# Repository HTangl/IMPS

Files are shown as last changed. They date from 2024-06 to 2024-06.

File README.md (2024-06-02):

# IMPS
Variable Impedance Selector  

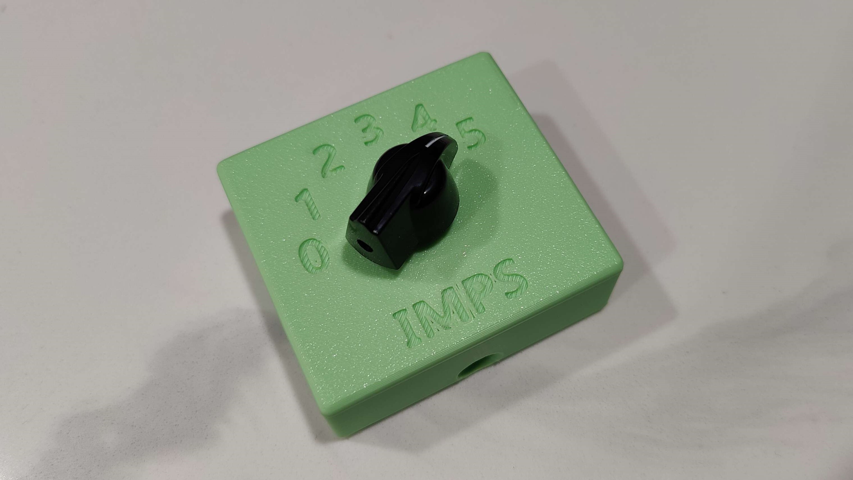
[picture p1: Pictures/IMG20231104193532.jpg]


The IMPS is a simple pcb made to allow switching between different sets of resistors to emulate output impedance. It was made to facilitate easy testing of impedance effects on headphones and iems.  

Parts list is as follows  

10 - 1/4 watt metal film resistors of varying values  
You can use any values you want but the original inteded values were R1-10, R2-20, R3-50, R4-75, R5-100  

2 - surface mount 3.5mm ports  
There are most likely a lot of different generic ports that will work here, I used some uxcell ones  
https://a.co/d/fRi1UGk  

1 - 2P6T rotary switch  
This needs to have surface mount pins not through hole legs as the holes on the PCB were not designed to fit those  
https://a.co/d/1c0tU72  

1 - 3.5mm male to 3.5mm male cable  
For connecting the IMPS input to desired source device

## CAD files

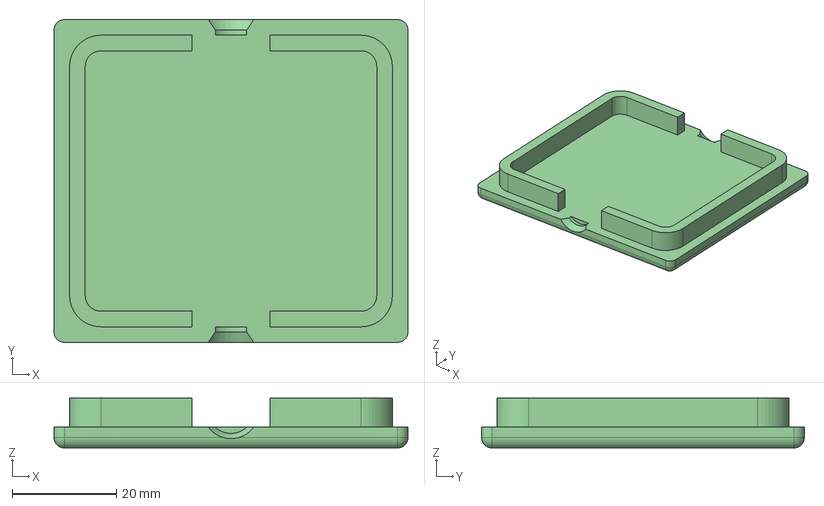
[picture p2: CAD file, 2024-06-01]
Case/Imps Case Bottom.step
68.0 x 62.0 x 9.60 mm

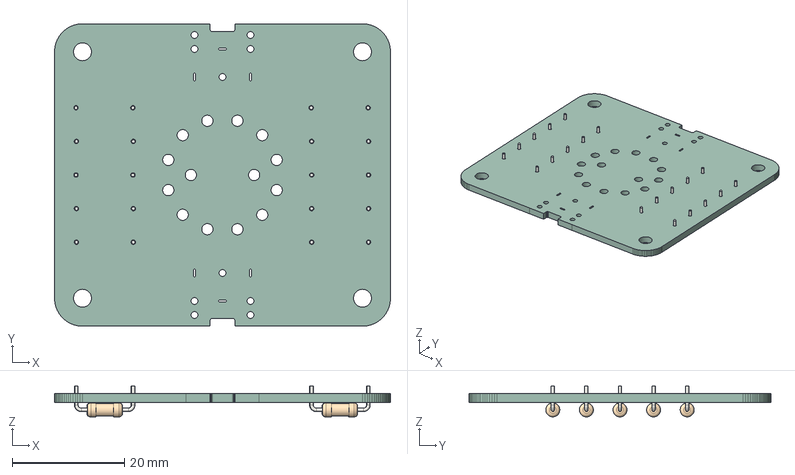
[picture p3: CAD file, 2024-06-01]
Kicad/Impedance Selector.step
60.0 x 54.0 x 5.50 mm
Impedance Selector PCB

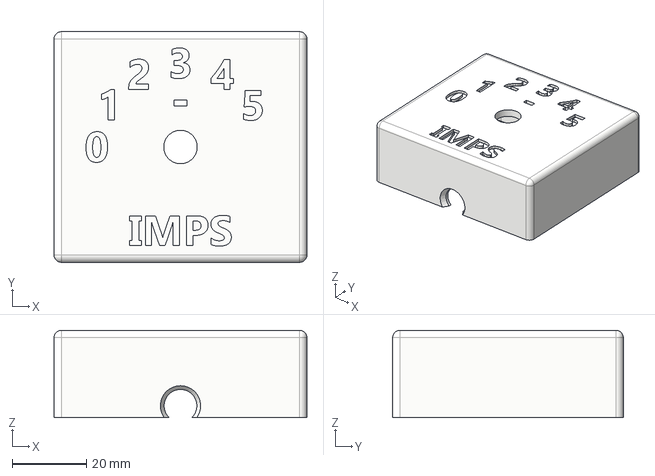
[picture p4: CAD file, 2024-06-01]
Case/IMPS Case Top.step
68.0 x 62.0 x 23.5 mm

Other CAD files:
Case/IMPS Case Bottom.stl
Case/IMPS Case Top.stl

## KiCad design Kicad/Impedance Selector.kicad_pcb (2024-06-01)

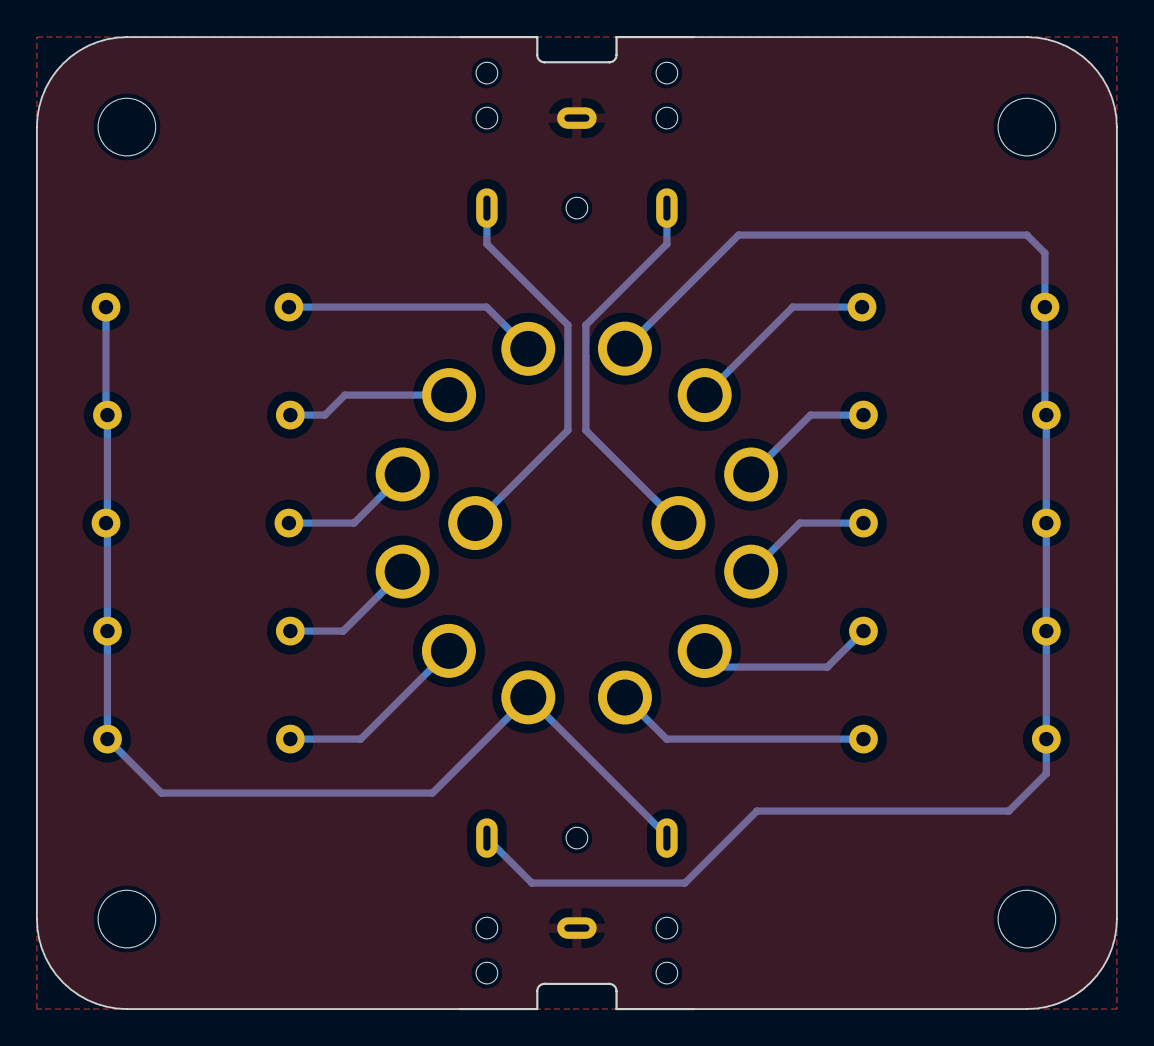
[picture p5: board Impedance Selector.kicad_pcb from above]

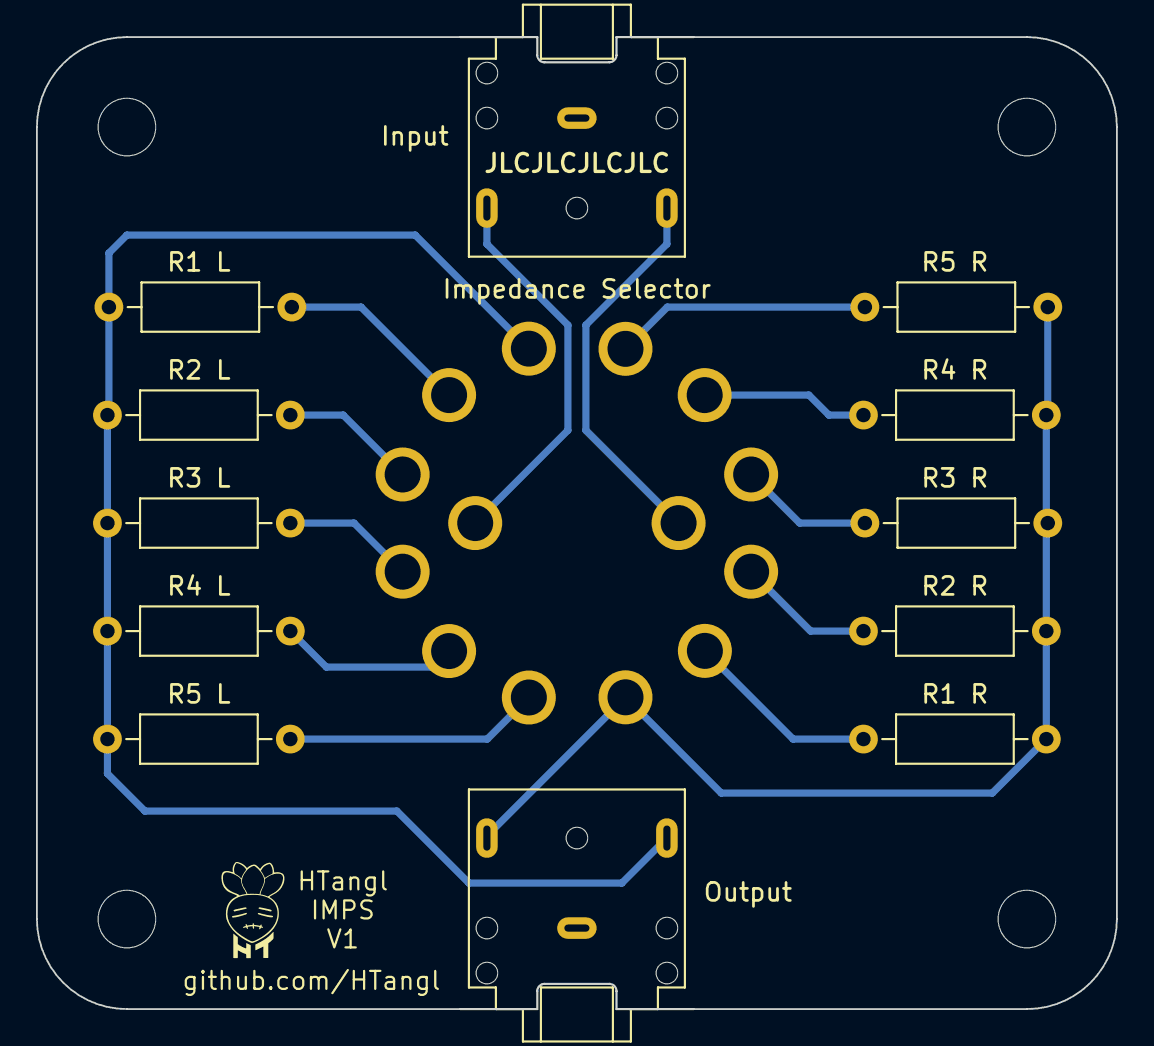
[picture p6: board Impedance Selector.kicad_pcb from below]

Board: 2 copper layers, 60.0 x 54.0 mm, 13 parts (12 on the bottom side), 15 nets.

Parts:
J1: Input; Jack_3.5mm_CUI_SJ1-3523N_Horizontal
J2: Output; Jack_3.5mm_CUI_SJ1-3523N_Horizontal
R1 L, R1 R: 10; R_Axial_DIN0207_L6.3mm_D2.5mm_P10.16mm_Horizontal
R2 L, R2 R: 20; R_Axial_DIN0207_L6.3mm_D2.5mm_P10.16mm_Horizontal
R3 L, R3 R: 50; R_Axial_DIN0207_L6.3mm_D2.5mm_P10.16mm_Horizontal
R4 L, R4 R: 75; R_Axial_DIN0207_L6.3mm_D2.5mm_P10.16mm_Horizontal
R5 L, R5 R: 100; R_Axial_DIN0207_L6.3mm_D2.5mm_P10.16mm_Horizontal
SW1: Impedance Selector; Rotary_Switch_2P6T

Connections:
GND: J1.S, J2.S
unnamed: J1.R, SW1.14
unnamed: J1.T, SW1.13
unnamed: J2.R, R1 R.2, R2 R.2, R3 R.2, R4 R.2, R5 R.2, SW1.7
unnamed: J2.T, R1 L.2, R2 L.2, R3 L.2, R4 L.2, R5 L.2, SW1.1
unnamed: R1 L.1, SW1.2
unnamed: R1 R.1, SW1.8
unnamed: R2 L.1, SW1.3
unnamed: R2 R.1, SW1.9
unnamed: R3 L.1, SW1.4
unnamed: R3 R.1, SW1.10
unnamed: R4 L.1, SW1.5
unnamed: R4 R.1, SW1.11
unnamed: R5 L.1, SW1.6
unnamed: R5 R.1, SW1.12
